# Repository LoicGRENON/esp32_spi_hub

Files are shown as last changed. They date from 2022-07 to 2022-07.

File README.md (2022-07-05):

SPI HUB for ESP32
=================
This repository contains the firmware source code and the hardware design
files.

The design is a fork of the ESP32 Brick from Tinkerforge : https://github.com/Tinkerforge/esp32-brick & https://www.tinkerforge.com/en/doc/Hardware/Bricks/ESP32_Brick.html

It is modified mainly to use "basic parts" components from JLCPCB for cost-effective assembly and also to use a ESP32 with external antenna (ESP32-WROOM-32UE-N16).

Hardware
--------

The hardware is designed with the open source EDA Suite KiCad 6.0 (http://www.kicad.org) and Kikit (https://github.com/yaqwsx/KiKit) is used to generate the assembly files.

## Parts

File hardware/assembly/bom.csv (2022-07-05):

Comment | Designator | Footprint | LCSC
0.1uF | C1,C3,C5,C7,C10,C12,C15,C22,C29 | Capacitor_SMD:C_0402_1005Metric | C1525
10uF | C2,C4,C8,C11 | Capacitor_Tantalum_SMD:CP_EIA-3216-18_Kemet-A | C7171
22uF | C6 | Capacitor_SMD:C_0603_1608Metric | C59461
10uF | C9 | Capacitor_SMD:C_0402_1005Metric | C15525
1nF | C13,C14 | Capacitor_SMD:C_0402_1005Metric | C1523
220pF | C16,C17,C18,C19,C20,C21,C23,C24,C25,C26,C27,C28,C30,C31,C32,C33,C34,C35 | Capacitor_SMD:C_0402_1005Metric | C1530
SS34 | D1 | Diode_SMD:D_SMA | C8678
YE | D2 | LED_SMD:LED_0603_1608Metric | C72038
GN | D3 | LED_SMD:LED_0603_1608Metric | C72043
BU | D4 | LED_SMD:LED_0603_1608Metric | C72041
100 @ 100MHz | FB1 | Resistor_SMD:R_0805_2012Metric | C1015
EXT_HEADER | J1 | Connector_PinHeader_2.00mm:PinHeader_1x08_P2.00mm_Vertical | -
SM07B-GHS-TB | J2,J3,J4,J5,J6,J7 | Connector_JST:JST_GH_SM07B-GHS-TB_1x07-1MP_P1.25mm_Horizontal | C495552
USB_C_Plug_USB2.0 | P1 | Connector_USB:USB_C_Receptacle_Palconn_UTC16-G | C709357
AO3401A | Q1 | Package_TO_SOT_SMD:SOT-23 | C15127
S8050 | Q2,Q3 | Package_TO_SOT_SMD:SOT-23 | C2146
4.7k | R1 | Resistor_SMD:R_0402_1005Metric | C25900
100 | R2,R9,R10,R11,R12,R13,R14,R23,R24,R25,R26,R30,R31,R32,R33,R35,R36,R37,R38,R42,R43,R44,R45,R47,R48,R49,R50,R54,R55,R56,R57 | Resistor_SMD:R_0402_1005Metric | C25076
12k | R3,R4,R5,R6 | Resistor_SMD:R_0402_1005Metric | C25752
DNP | R7,R8 | Resistor_SMD:R_0402_1005Metric | -
5.1k | R15,R16 | Resistor_SMD:R_0402_1005Metric | C25905
470 | R17,R21 | Resistor_SMD:R_0402_1005Metric | C25117
1k | R18,R19,R20 | Resistor_SMD:R_0402_1005Metric | C11702
100k | R22,R27,R34,R39,R46,R51 | Resistor_SMD:R_0402_1005Metric | C25741
10k | R28,R29,R40,R41,R52,R53 | Resistor_SMD:R_0402_1005Metric | C25744
1k | RN1 | Resistor_SMD:R_Array_Convex_4x0603 | C20197
SW_Push | SW1,SW2 | Button_Switch_SMD:SW_SPST_B3U-1000P-B | -
AMS1117-3.3 | U1 | Package_TO_SOT_SMD:SOT-223-3_TabPin2 | C6186
CP2102-GMR | U2 | Package_DFN_QFN:QFN-28-1EP_5x5mm_P0.5mm_EP3.35x3.35mm | C6568
ESP32-WROOM-32UE-N16 | U3 | RF_Module:ESP32-WROOM-32U | -
82400152 | U4 | Package_TO_SOT_SMD:SOT-563 | -
74HC244 | U5,U6,U7 | Package_SO:TSSOP-20_4.4x6.5mm_P0.65mm | C6835

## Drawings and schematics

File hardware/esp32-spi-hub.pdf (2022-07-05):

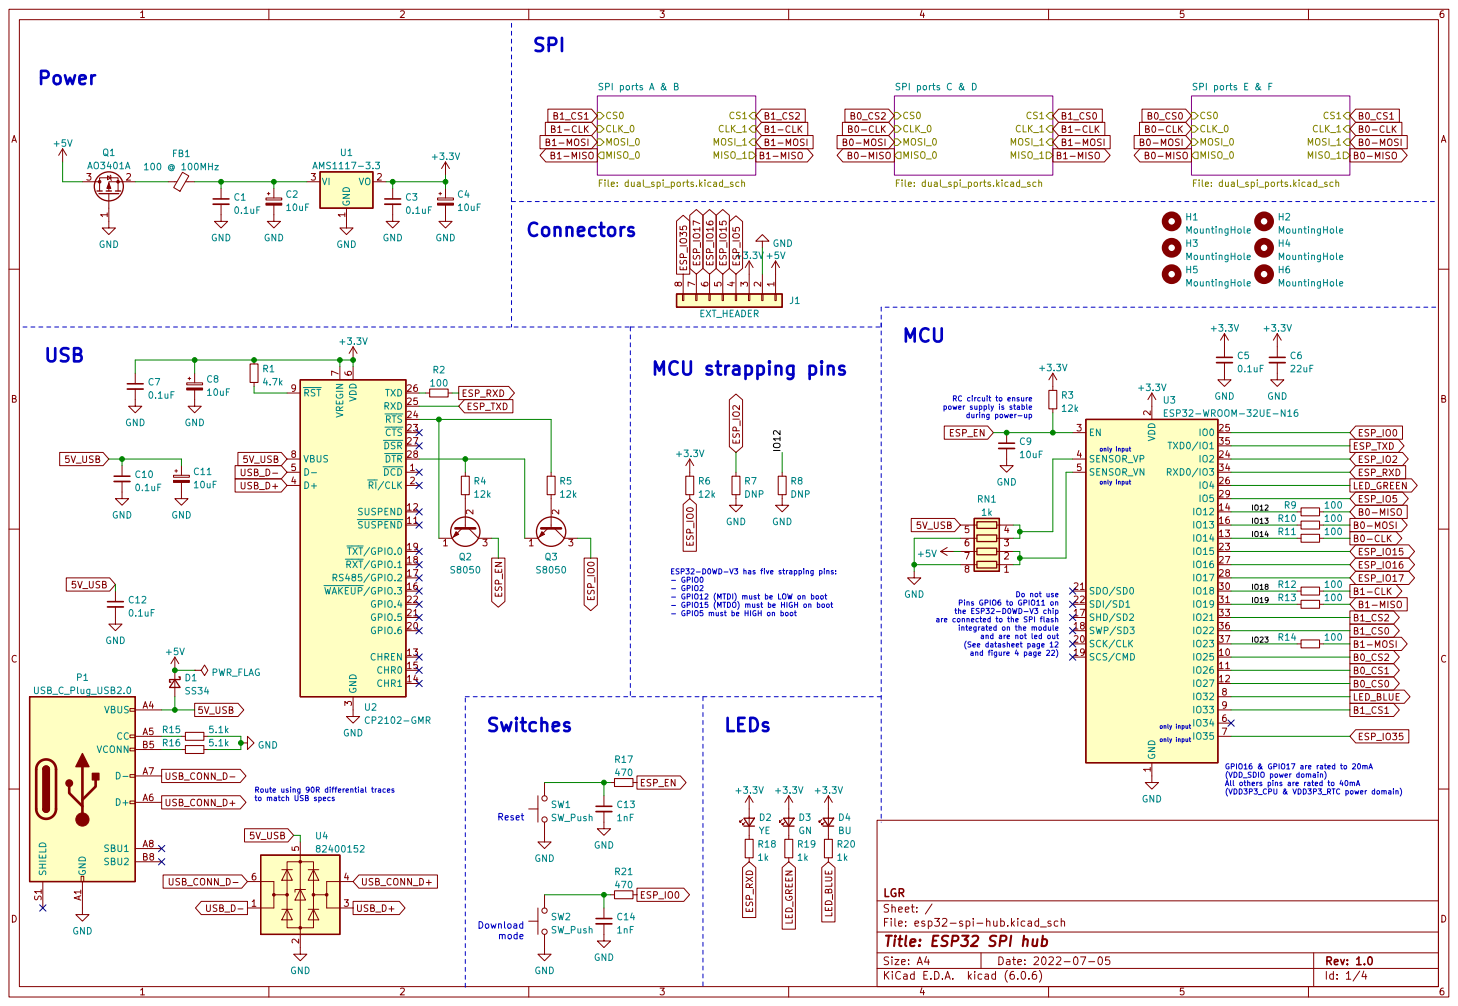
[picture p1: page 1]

1 VO 2 VI 3 U1 AMS1117-3.3 GND GND

7 VBUS 8 ~{RST} 9 U2CP2102-GMR GND

ESP_TXD
during power-up Download mode

RC circuit to ensure
power supply is stable

2 SCK/CLK 20 SDO/SD0 21 SDI/SD1 22

IO14 ESP32-D0WD-V3 has five strapping pins: - GPIO0

- GPIO2
- GPIO12 (MTDI) must be LOW on boot - GPIO15 (MTDO) must be HIGH on boot - GPIO5 must be HIGH on boot LEDs

(VDD3P3_CPU & VDD3P3_RTC power domain) Do not use Pins GPIO6 to GPIO11 on

the ESP32-D0WD-V3 chip
are connected to the SPI flash
integrated on the module
and are not led out (See datasheet page 12

and figure 4 page 22) Reset

only input only input Switches

GPIO16 & GPIO17 are rated to 20mA
(VDD_SDIO power domain) All others pins are rated to 40mA

Route using 90R differential traces
to match USB specs

File: esp32-spi-hub.kicad_sch Sheet: / LGR

Id: 1/4 Title: ESP32 SPI hub

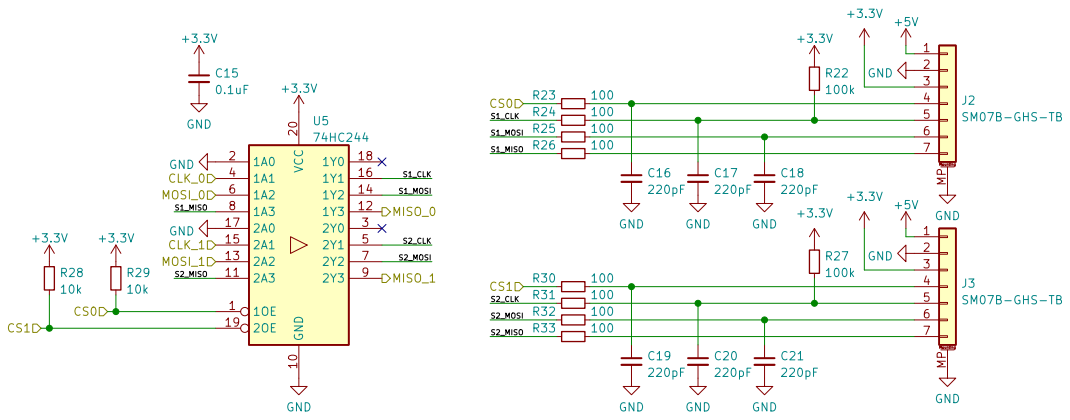
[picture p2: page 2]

Sheet: /SPI ports A & B/ LGR

File: dual_spi_ports.kicad_sch
Id: 2/4 Title: ESP32 SPI hub - SPI ports

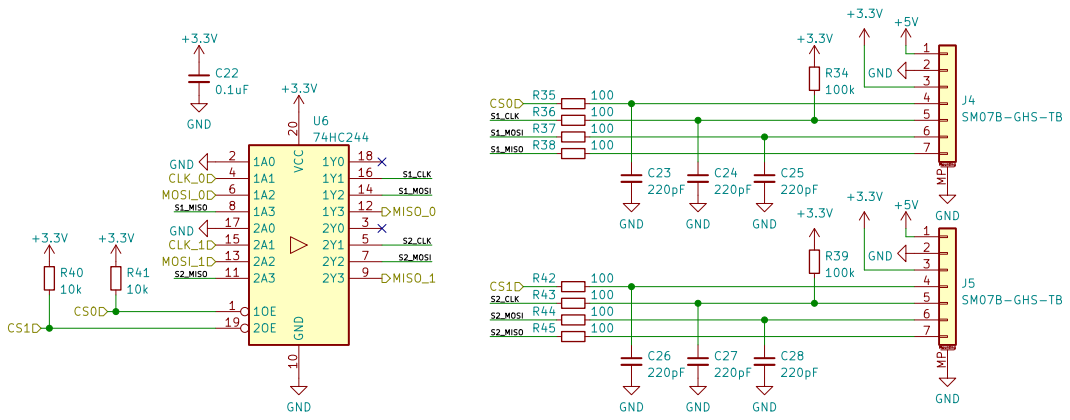
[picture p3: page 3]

Sheet: /SPI ports C & D/ LGR

File: dual_spi_ports.kicad_sch
Id: 3/4 Title: ESP32 SPI hub - SPI ports

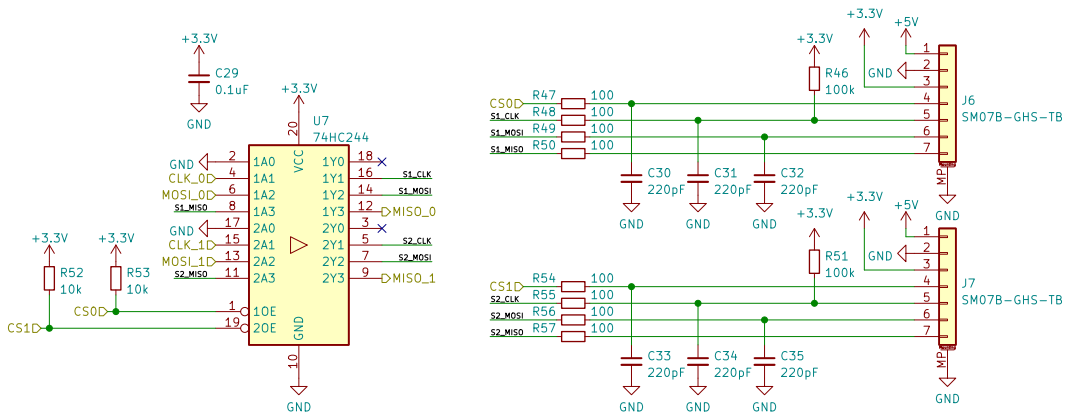
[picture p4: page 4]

Sheet: /SPI ports E & F/ LGR

File: dual_spi_ports.kicad_sch
Id: 4/4 Title: ESP32 SPI hub - SPI ports

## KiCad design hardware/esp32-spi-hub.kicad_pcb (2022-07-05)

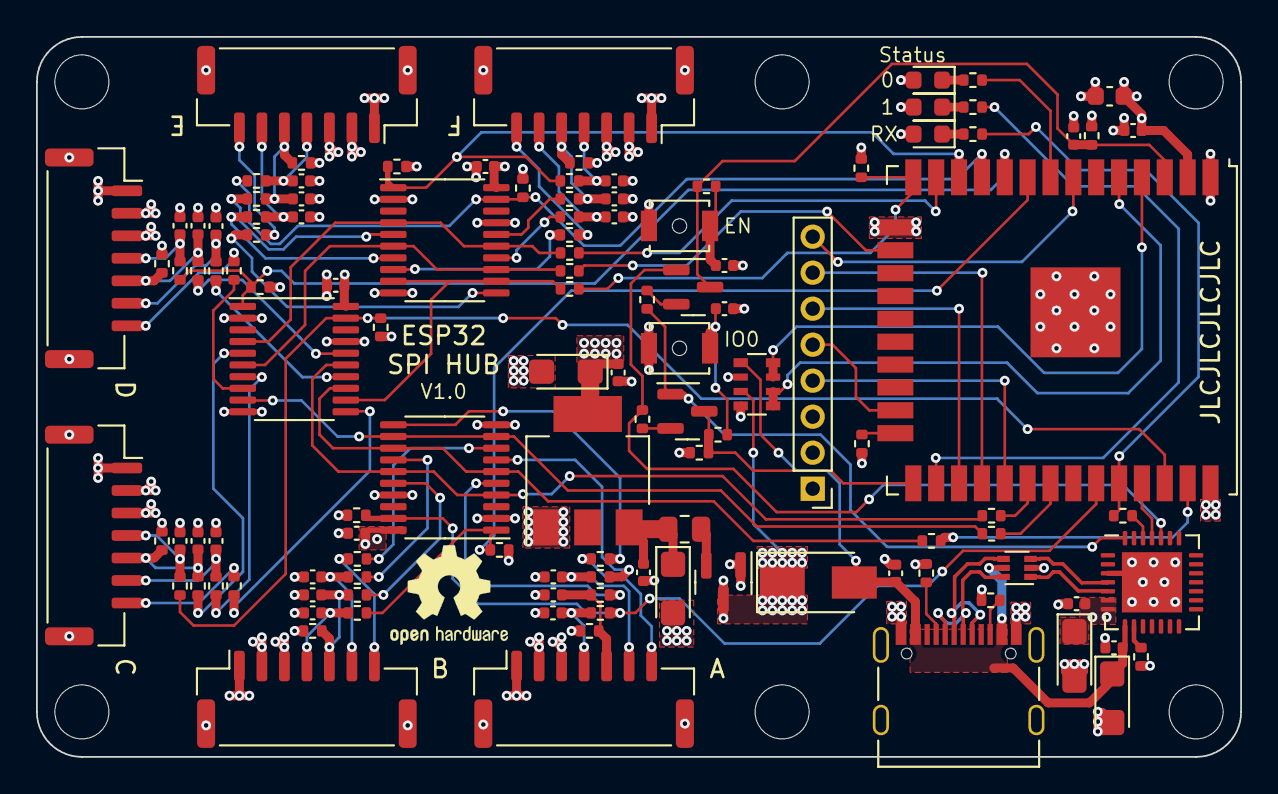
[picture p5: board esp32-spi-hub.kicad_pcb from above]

Board: 4 copper layers, 66.9 x 40.0 mm, 124 parts (0 on the bottom side), 97 nets.

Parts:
C1, C3, C5, C7, C10, C12, C15, C22, C29: 0.1uF; C_0402_1005Metric
C2, C4, C8, C11: 10uF; CP_EIA-3216-18_Kemet-A
C6: 22uF; C_0603_1608Metric
C9: 10uF; C_0402_1005Metric
C13, C14: 1nF; C_0402_1005Metric
C16, C17, C18, C19, C20, C21, C23, C24, C25, C26, C27, C28, C30, C31, C32, C33, C34, C35: 220pF; C_0402_1005Metric
D1: SS34; D_SMA
D2: YE; LED_0603_1608Metric
D3: GN; LED_0603_1608Metric
D4: BU; LED_0603_1608Metric
FB1: 100 @ 100MHz; R_0805_2012Metric
H1, H2, H3, H4, H5, H6: MountingHole; MountingHole_3mm
J1: EXT_HEADER; PinHeader_1x08_P2.00mm_Vertical
J2, J3, J4, J5, J6, J7: SM07B-GHS-TB; JST_GH_SM07B-GHS-TB_1x07-1MP_P1.25mm_Horizontal
P1: USB_C_Plug_USB2.0; USB_C_Receptacle_Palconn_UTC16-G
Q1: AO3401A; SOT-23
Q2, Q3: S8050; SOT-23
R1: 4.7k; R_0402_1005Metric
R2, R9, R10, R11, R12, R13, R14, R23, R24, R25, R26, R30, R31, R32, R33, R35, R36, R37, R38, R42, R43, R44, R45, R47, R48, R49, R50, R54, R55, R56, R57: 100; R_0402_1005Metric
R3, R4, R5, R6: 12k; R_0402_1005Metric
R7, R8: DNP; R_0402_1005Metric
R15, R16: 5.1k; R_0402_1005Metric
R17, R21: 470; R_0402_1005Metric
R18, R19, R20: 1k; R_0402_1005Metric
R22, R27, R34, R39, R46, R51: 100k; R_0402_1005Metric
R28, R29, R40, R41, R52, R53: 10k; R_0402_1005Metric
RN1: 1k; R_Array_Convex_4x0603
SW1, SW2: SW_Push; SW_SPST_B3U-1000P-B
U1: AMS1117-3.3; SOT-223-3_TabPin2
U2: CP2102-GMR; QFN-28-1EP_5x5mm_P0.5mm_EP3.35x3.35mm
U3: ESP32-WROOM-32UE-N16; ESP32-WROOM-32U
U4: 82400152; SOT-563
U5, U6, U7: 74HC244; TSSOP-20_4.4x6.5mm_P0.65mm

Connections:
5V_USB: C10.1, C11.1, C12.1, D1.2 (A), P1.A4 (VBUS), P1.A9 (VBUS), P1.B4 (VBUS), P1.B9 (VBUS), RN1.5 (R4.2), U2.8 (VBUS), U4.5 (VBUS)
+3V3: C3.1, C4.1, C5.1, C6.1, C7.1, C8.1, C15.1, C22.1, C29.1, D2.2 (A), D3.2 (A), D4.2 (A), J1.3, J2.3, J3.3, J4.3, J5.3, J6.3, J7.3, R1.1, R3.1, R6.1, R22.1, R27.1, R28.1, R29.1, R34.1, R39.1, R40.1, R41.1, R46.1, R51.1, R52.1, R53.1, U1.2 (VO), U2.6 (VDD), U2.7 (VREGIN), U3.2 (VDD), U5.20 (VCC), U6.20 (VCC), U7.20 (VCC)
+5V: D1.1 (K), J1.1, J2.1, J3.1, J4.1, J5.1, J6.1, J7.1, Q1.3 (D), RN1.7 (R2.2)
/IO12: R8.1, R9.1, U3.14 (IO12)
/IO13: R10.1, U3.16 (IO13)
/IO14: R11.1, U3.13 (IO14)
/IO18: R12.1, U3.30 (IO18)
/IO19: R13.1, U3.31 (IO19)
/IO23: R14.1, U3.37 (IO23)
/SPI ports A & B/S1_CLK: R24.1, U5.16 (1Y1)
/SPI ports A & B/S1_MISO: R26.1, U5.8 (1A3)
/SPI ports A & B/S1_MOSI: R25.1, U5.14 (1Y2)
/SPI ports A & B/S2_CLK: R31.1, U5.5 (2Y1)
/SPI ports A & B/S2_MISO: R33.1, U5.11 (2A3)
/SPI ports A & B/S2_MOSI: R32.1, U5.7 (2Y2)
/SPI ports C & D/S1_CLK: R36.1, U6.16 (1Y1)
/SPI ports C & D/S1_MISO: R38.1, U6.8 (1A3)
/SPI ports C & D/S1_MOSI: R37.1, U6.14 (1Y2)
/SPI ports C & D/S2_CLK: R43.1, U6.5 (2Y1)
/SPI ports C & D/S2_MISO: R45.1, U6.11 (2A3)
/SPI ports C & D/S2_MOSI: R44.1, U6.7 (2Y2)
/SPI ports E & F/S1_CLK: R48.1, U7.16 (1Y1)
/SPI ports E & F/S1_MISO: R50.1, U7.8 (1A3)
/SPI ports E & F/S1_MOSI: R49.1, U7.14 (1Y2)
/SPI ports E & F/S2_CLK: R55.1, U7.5 (2Y1)
/SPI ports E & F/S2_MISO: R57.1, U7.11 (2A3)
/SPI ports E & F/S2_MOSI: R56.1, U7.7 (2Y2)
B0-CLK: R11.2, U6.4 (1A1), U7.4 (1A1), U7.15 (2A1)
B0-MISO: R9.2, U6.12 (1Y3), U7.9 (2Y3), U7.12 (1Y3)
B0-MOSI: R10.2, U6.6 (1A2), U7.6 (1A2), U7.13 (2A2)
B0_CS0: R47.1, R53.2, U3.12 (IO27), U7.1 (1OE)
B0_CS1: R52.2, R54.1, U3.11 (IO26), U7.19 (2OE)
B0_CS2: R35.1, R41.2, U3.10 (IO25), U6.1 (1OE)
B1-CLK: R12.2, U5.4 (1A1), U5.15 (2A1), U6.15 (2A1)
B1-MISO: R13.2, U5.9 (2Y3), U5.12 (1Y3), U6.9 (2Y3)
B1-MOSI: R14.2, U5.6 (1A2), U5.13 (2A2), U6.13 (2A2)
B1_CS0: R40.2, R42.1, U3.36 (IO22), U6.19 (2OE)
B1_CS1: R23.1, R29.2, U3.9 (IO33), U5.1 (1OE)
B1_CS2: R28.2, R30.1, U3.33 (IO21), U5.19 (2OE)
ESP_EN: C9.1, Q2.3 (C), R3.2, R17.2, U3.3 (EN)
ESP_IO0: Q3.3 (C), R6.2, R21.2, U3.25 (IO0)
ESP_IO2: R7.1, U3.24 (IO2)
ESP_IO5: J1.4, U3.29 (IO5)
ESP_IO15: J1.5, U3.23 (IO15)
ESP_IO16: J1.6, U3.27 (IO16)
ESP_IO17: J1.7, U3.28 (IO17)
ESP_IO35: J1.8, U3.7 (IO35)
ESP_RXD: R2.2, R18.2, U3.34 (RXD0/IO3)
ESP_TXD: U2.25 (RXD), U3.35 (TXD0/IO1)
GND: C1.2, C2.2, C3.2, C4.2, C5.2, C6.2, C7.2, C8.2, C9.2, C10.2, C11.2, C12.2, C13.2, C14.2, C15.2, C16.2, C17.2, C18.2, C19.2, C20.2, C21.2, C22.2, C23.2, C24.2, C25.2, C26.2, C27.2, C28.2, C29.2, C30.2, C31.2, C32.2, C33.2, C34.2, C35.2, J1.2, J2.2, J2.MP (MountPin), J3.2, J3.MP (MountPin), J4.2, J4.MP (MountPin), J5.2, J5.MP (MountPin), J6.2, J6.MP (MountPin), J7.2, J7.MP (MountPin), P1.A1 (GND), P1.A12 (GND), P1.B1 (GND), P1.B12 (GND), Q1.1 (G), R7.2, R8.2, R15.2, R16.2, RN1.6 (R3.2), RN1.8 (R1.2), SW1.1, SW2.1, U1.1 (GND), U2.3 (GND), U2.29 (GND), U3.1 (GND), U3.15 (GND), U3.38 (GND), U3.39 (GND), U4.2 (GND), U5.2 (1A0), U5.10 (GND), U5.17 (2A0), U6.2 (1A0), U6.10 (GND), U6.17 (2A0), U7.2 (1A0), U7.10 (GND), U7.17 (2A0)
LED_BLUE: R20.2, U3.8 (IO32)
LED_GREEN: R19.2, U3.26 (IO4)
unnamed: C1.1, C2.1, FB1.2, U1.3 (VI)
unnamed: C13.1, R17.1, SW1.2
unnamed: C14.1, R21.1, SW2.2
unnamed: C16.1, J2.4, R23.2
unnamed: C17.1, J2.5, R22.2, R24.2
unnamed: C18.1, J2.6, R25.2
unnamed: C19.1, J3.4, R30.2
unnamed: C20.1, J3.5, R27.2, R31.2
unnamed: C21.1, J3.6, R32.2
unnamed: C23.1, J4.4, R35.2
unnamed: C24.1, J4.5, R34.2, R36.2
unnamed: C25.1, J4.6, R37.2
unnamed: C26.1, J5.4, R42.2
unnamed: C27.1, J5.5, R39.2, R43.2
unnamed: C28.1, J5.6, R44.2
unnamed: C30.1, J6.4, R47.2
unnamed: C31.1, J6.5, R46.2, R48.2
unnamed: C32.1, J6.6, R49.2
unnamed: C33.1, J7.4, R54.2
unnamed: C34.1, J7.5, R51.2, R55.2
unnamed: C35.1, J7.6, R56.2
unnamed: D2.1 (K), R18.1
unnamed: D3.1 (K), R19.1
unnamed: D4.1 (K), R20.1
unnamed: FB1.1, Q1.2 (S)
unnamed: J2.7, R26.2
unnamed: J3.7, R33.2
unnamed: J4.7, R38.2
unnamed: J5.7, R45.2
unnamed: J6.7, R50.2
unnamed: J7.7, R57.2
unnamed: P1.A5 (CC), R15.1
unnamed: P1.B5 (VCONN), R16.1
unnamed: Q2.1 (E), R5.1, U2.24 (~RTS)
unnamed: Q2.2 (B), R4.2
unnamed: Q3.1 (E), R4.1, U2.28 (~DTR)
unnamed: Q3.2 (B), R5.2
unnamed: R1.2, U2.9 (~RST)
unnamed: R2.1, U2.26 (TXD)
unnamed: RN1.1 (R1.1), RN1.2 (R2.1), U3.5 (SENSOR_VN)
unnamed: RN1.3 (R3.1), RN1.4 (R4.1), U3.4 (SENSOR_VP)
USB_CONN_D+: P1.A6 (D+), P1.B6 (D+), U4.4 (I/O2)
USB_CONN_D-: P1.A7 (D-), P1.B7 (D-), U4.6 (I/O1)
USB_D+: U2.4 (D+), U4.3 (I/O2)
USB_D-: U2.5 (D-), U4.1 (I/O1)

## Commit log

2022-07-05 Add PDF schematics
    [dual_spi_ports.kicad_sch, esp32-spi-hub.kicad_sch]
2022-07-05 Add JLCJLCJLCJLC on silkscreen for part number removal
    [esp32-spi-hub-CmtUser.gbr, esp32-spi-hub-CuBottom.gbl, esp32-spi-hub-CuTop.gtl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]
